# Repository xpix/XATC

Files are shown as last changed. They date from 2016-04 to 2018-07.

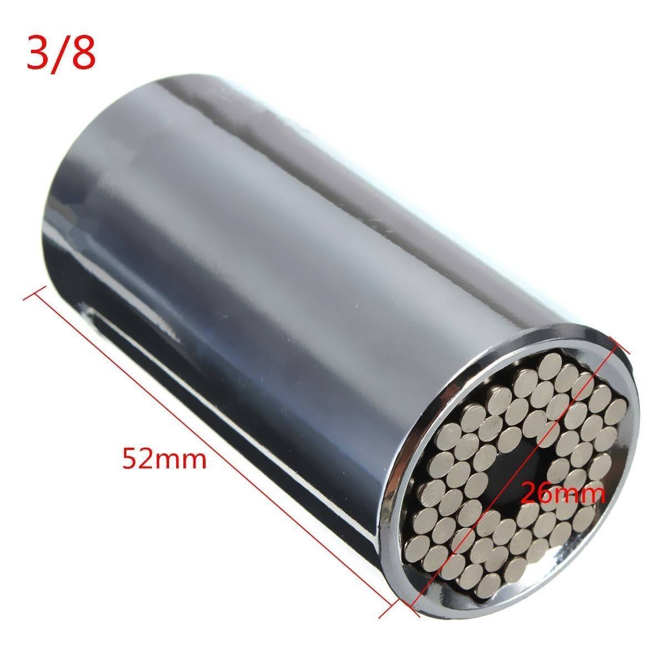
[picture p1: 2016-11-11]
pics/61zgxAEAy0L._SL1200_.jpg

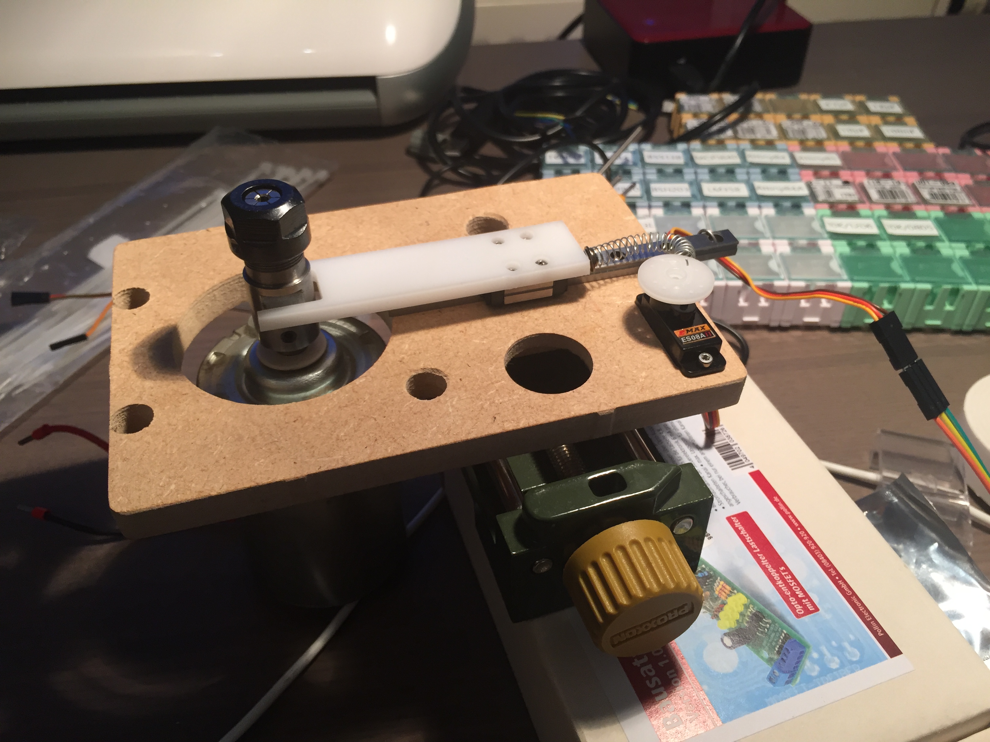
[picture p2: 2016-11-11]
pics/IMG_0800.JPG

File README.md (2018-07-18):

XATC
====

For my XDisPlace project i try to find a good solution to bring all (Mill, Cut, Drill, Solder dispense, Solder) processes together. 
I wrote a ToDo what i need to bring this project to fly. I realized, all what i need it's just to find a solution for an Automatic Tool Changer (ATC).
Here i try to describe all steps how you can build your own XATC.

Full endmill change (https://www.youtube.com/watch?v=-IGAYd8OnOE)

![Some Prototypes](https://lh3.googleusercontent.com/1o3ptjsWJQUGR22RlypUTsi2ktSJ3byGEMolx_pXxnDRvq5ogUWD7ulUHWkvxa8qtrL7SXkMepEVHm6FAdkG-Nc4atV2e4KjoQi_63OzVnHIrBEG3auFcek6qWjRMISj2B0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)

Project Links
------------
* Weekly messages on [g+](https://plus.google.com/collection/QX47gB)
* Video sessions on [youtube](https://www.youtube.com/playlist?list=PLYPTUTcLMTK7m0cOoOKlDnuhGV8ONrgo_)
* Web Video log on [blogspot](http://xpixer.blogspot.com/)

Dependencies
------------

* [TinyG as CNC Controller](https://github.com/synthetos/TinyG)
  The first stable version is realized on a tinyGv8.
* [Chilipeppr](http://chilipeppr.com/tinyg)
  This will be needed at runtime to perform the actual tool change.
* [Arduino](https://www.arduino.cc/)
  Only required for Servo control support.
* [CNC3040](http://www.ebay.com/bhp/cnc-3040z)
  The hardware platform that i use for this project

Components
----------
On the follow pages i'll describe the diy mechanical parts that you can mill on your CNC3040.

* [Spindle lock platform](https://github.com/xpix/XATC/wiki/Spindle-lock-platform)
  All about lock the spindle, drafts, software and BOM List's
* [XATC Carousel](https://github.com/xpix/XATC/wiki/XATC-Carousel)
  All about the central component, the xatc carousel ...

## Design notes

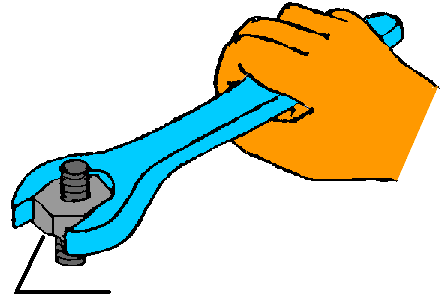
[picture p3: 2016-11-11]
pics/Hebel_Bild_12.gif

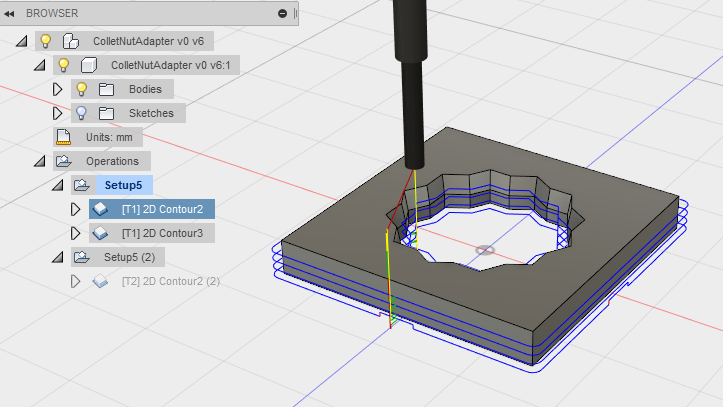
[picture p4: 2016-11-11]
pics/FusionSimulate.PNG

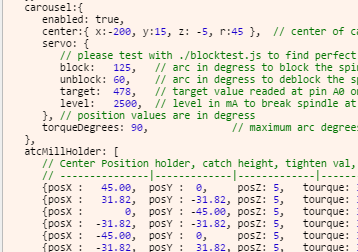
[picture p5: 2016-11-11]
pics/code.PNG

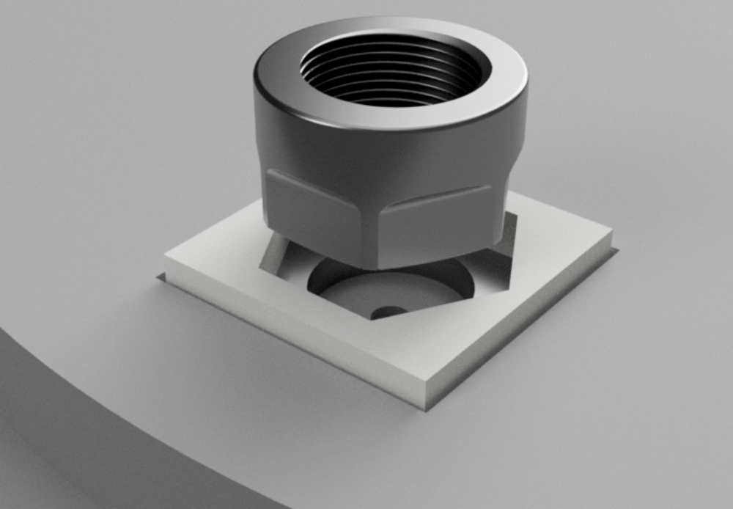
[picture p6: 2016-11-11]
pics/CarouselV2 v6.png

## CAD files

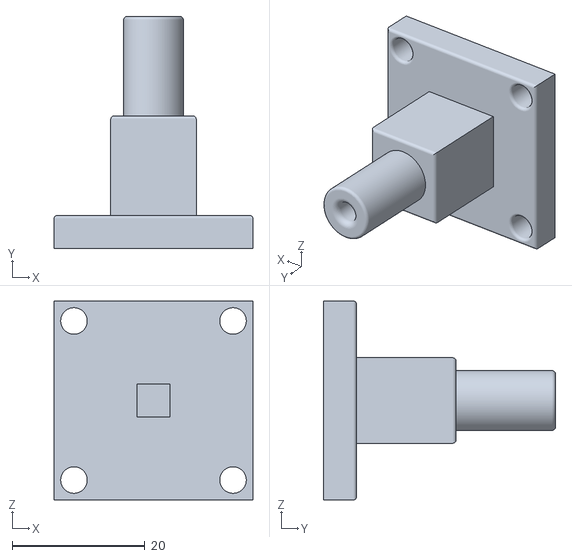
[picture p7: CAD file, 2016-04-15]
fusion360/XTC-Holder.stl
30.0 x 35.0 x 30.0

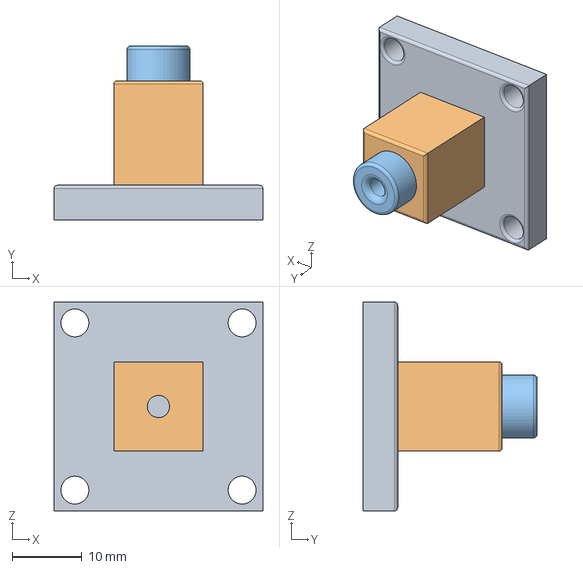
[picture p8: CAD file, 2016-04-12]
fusion360/XTC-Holder v0.step
30.0 x 25.0 x 30.0 mm

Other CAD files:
fusion360/GatorGripAdapter v2.f3d
fusion360/XTC-Holder v0.iges
fusion360/XTC-Holder.f3d

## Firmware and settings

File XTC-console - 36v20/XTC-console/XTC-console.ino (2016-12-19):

/*
The XTC Console program to communicate between chilipeppr and motordriver. 
Use a normal arduino nano at this time and send textcommands (a kind of g-code for spindle)
Please use this DC Controller (30A High Power Single way H-bridge DC Motor Driver Module) http://www.ebay.com/itm/131528092776 
and a ACS712 Current sensor

Use this pinout:
ACS712: 
  VCC --> 5V
  SIG --> A0
  3.3 --> A5
  GND --> GND

DC Controller
  GND --> GND
  PA  --> D9
  A1  --> D2
  A2  --> D4

PWM Signal from CNC Controller
  PWM --> D3
  GND --> GND
  
*/

// Demo Code for SerialCommand Library Steven Cogswell May 2011
// https://github.com/scogswell/ArduinoSerialCommand

#include "SerialCommand.h"
#include "HighPowerMotorDriver.h"
#include "Timer.h"
#include <Servo.h>


#define servoPin A0           // Arduino Servo Pin
#define arduinoLED 13         // Arduino LED on board
#define pwmPin 3              // PWM read pin

#define defaultSpeed 100      // Default speed for spindle
#define defaultBreak 400      // Default power for breake 
#define interval 50           // interval in milliseconds to test the motor current

int level   = 0;
int currentEvent;
int debugEvent;
int speed;
int saved_speed;
int pwm_value;
int speedTimer;


SerialCommand SCmd;        // The SerialCommand object
HighPowerMotorDriver md;
Timer timer;               // The timer object
Servo myservo;                // create servo object to control a servo

void servo_control()
{
  int pos = 91;
  char *arg = SCmd.next();    // Get the next argument from the SerialCommand object buffer
  if (arg != NULL)      // As long as it existed, take it
  {
      pos = atol(arg);
  }

  spindle_pwm(false);
  myservo.write(pos); 
  delay(100);   

  ok();
}


// fwd 400 500
void spindle_forward()
{
  speed = defaultSpeed;
  spindle_pwm(false);

  char *arg = SCmd.next();    // Get the next argument from the SerialCommand object buffer
  if (arg != NULL)      // As long as it existed, take it
  {
      speed = atol(arg);
  }
  else if(saved_speed) {
      speed = saved_speed;
  }

  // Timer parameter 
  arg = SCmd.next();
  int timee = 0;
  if (arg != NULL){
    timee = atol(arg);
    callTimer(timee);
  }

  spindle_status(speed, timee);

  md.setSpeed(speed);
  ok();
}

// bwd 400 500
void spindle_backward()
{
  speed = (0 - defaultSpeed);
  spindle_pwm(false);

  char *arg = SCmd.next();    // Get the next argument from the SerialCommand object buffer
  if (arg != NULL)      // As long as it existed, take it
  {
      speed = (0 - atol(arg));
  }
  else if(saved_speed) {
      speed = saved_speed;
  }

  // Timer parameter 
  arg = SCmd.next();
  int timee = 0;
  if (arg != NULL){
    timee = atol(arg);
    callTimer(timee);
  }

  spindle_status(speed, timee);

  md.setSpeed(speed);
  ok();
}

void spindle_jitter()
{
  int time = 0;
  int speed = 0;
  spindle_pwm(false);

  // Speed parameter 
  char *arg = SCmd.next();    // Get the next argument from the SerialCommand object buffer
  if (arg != NULL)      // As long as it existed, take it
  {
      speed = atol(arg);
  }

  // Timer parameter 
  arg = SCmd.next();
  if (arg != NULL){
    time = atol(arg);
  }

  // jitter one times forward i.e. speed 200 - time 100ms
  saved_speed = speed;
  spindle_forward();                      // drive spindle forward
  timer.after(time, spindle_break);       // 100ms: break spindle

  // ... and backward
  saved_speed = (0 - speed);
  timer.after(time+10, spindle_backward); // 110ms: drive spindle backward
  timer.after((time*2)+10, spindle_break);// 210ms: break spindle
}

// brk 300
void spindle_break()
{
  int breake = defaultBreak;
  spindle_pwm(false);

  char *arg = SCmd.next();    // Get the next argument from the SerialCommand object buffer
  if (arg != NULL)      // As long as it existed, take it
  {
      breake = atol(arg);
  }

  spindle_status(0, -1);
  
  md.setBrake();
  ok();
}

void set_dbg(){
  int dbg_interval = interval;
  char *arg = SCmd.next();    // Get the next argument from the SerialCommand object buffer
  if (arg != NULL)      // As long as it existed, take it
  {
      dbg_interval = atol(arg);
  }
  if(debugEvent){
      timer.stop(debugEvent);
      debugEvent = 0;
  }
  else {
      debugEvent = timer.every(dbg_interval, spindle_status);
  }
  ok();   
}

// sta
void spindle_status()
{
  spindle_status(0,0);
}

void spindle_status(int speed, int timee)
{
  int ma    = md.getCurrentMilliamps();

  Serial.print("Sp: "); 
  Serial.print(speed); 
  Serial.print("\t"); 

  Serial.print("PWM: "); 
  Serial.print(pwm_value); 
  Serial.print("\t"); 

  Serial.print("Tim: "); 
  Serial.print(timee); 
  Serial.print(" ms"); 
  Serial.print("\t"); 

  Serial.print("Cur: "); 
  Serial.print(ma); 
  Serial.print(" mA"); 
  Serial.print("\t"); 

  Serial.print("Lev: "); 
  Serial.print(level); 

  Serial.println(); 
}

// lev 3000
void spindle_set_breaklevel(){
  char *arg = SCmd.next();    // Get the next argument from the SerialCommand object buffer
  if (arg == NULL)      // As long as it existed, take it
  {
     Serial.print(F("lev: ")); 
     Serial.println(level); 
  }
  else{
      level = atol(arg);
  }
  ok();   
}

// tim 1000
// stop spindle after x milliseconds
void spindle_set_stoptime(){
  char *arg = SCmd.next();    // Get the next argument from the SerialCommand object buffer
  if (arg == NULL)      // As long as it existed, take it
  {
     Serial.print(F("tim: millisceonds")); 
  }
  else{
      int time = atol(arg);
      int waitEvent = callTimer(time);
  }
  ok();   
}

int callTimer(int time){
  return timer.after(time, spindle_break);
}

void ok(){
  Serial.println("OK"); 
}

void checkCurrent(){
   if( level > 0 && md.getCurrentMilliamps() >= level){
      timer.stop(currentEvent);
      md.setBrake(); // full brake
      level = 0;          // reset level
      currentEvent = timer.every(interval, checkCurrent);
   }

   if( level < 0 && md.getCurrentMilliamps() <= (0 - level)){
      timer.stop(currentEvent);
      md.setBrake(); // full brake
      level = 0;          // reset level
      currentEvent = timer.every(interval, checkCurrent);
   }
}

void set_led(){
  if(digitalRead(arduinoLED)){
      digitalWrite(arduinoLED,LOW);
  }
  else {
      digitalWrite(arduinoLED,HIGH);
  }
  ok();   
}

void spindle_pwm(){
  char *arg = SCmd.next();    // Get the next argument from the SerialCommand object buffer
  if (arg == NULL)            // As long as it existed, take it
  {
     spindle_pwm(true);
  }
  else
  {
     spindle_pwm(false);
  }
}

void spindle_pwm(bool active){
   if(active){
      // set a timer he read the pwm signal and set the spindle speed
      if(pwm_value > 0){
        md.setSpeed(pwm_value);
      } else {
        md.setSpeed(0);
      }
      speedTimer = timer.after(250, spindle_pwm);
   }else{
      if(speedTimer){
         timer.stop(speedTimer);
         speedTimer = 0;
         md.setSpeed(0);
      }
   }
}


// This gets set as the default handler, and gets called when no other command matches. 
void unrecognized()
{
  Serial.println(F("? use commands: fwd[S,T], bwd[S,T], jit[S,T] brk[I], sta, lev, tim[ms], srv[deg], dbg, sav, rem")); 
}

void setup()
{  
  pinMode(arduinoLED,OUTPUT);      // Configure the onboard LED for output
  digitalWrite(arduinoLED,LOW);    // default to LED off

  pinMode(pwmPin, INPUT);          // Pin to read PWM Value from CNC Controller

  Serial.begin(115200); 

  // Initialize Servo
  myservo.attach(servoPin);

  // Initialize motordriver
  md.init();

  // Setup callbacks for SerialCommand commands 
  SCmd.addCommand("srv",servo_control);         // Send commands to servo
  SCmd.addCommand("fwd",spindle_forward);       // Turns spindle on and rotate forward
  SCmd.addCommand("bwd",spindle_backward);      // Turns spindle on and rotate backward
  SCmd.addCommand("jit",spindle_jitter);        // Turns spindle rotate forward and backward
  SCmd.addCommand("brk",spindle_break);         // Turns Spindle w/ break power or defaultBreak
  SCmd.addCommand("sta",spindle_status);        // get milliamps and direction ...
  SCmd.addCommand("lev",spindle_set_breaklevel);// Set the level off millAmpere , the spindle will break
  SCmd.addCommand("tim",spindle_set_stoptime);  // Set delay to stop
  SCmd.addCommand("led",set_led);               // Set led on/off
  SCmd.addCommand("dbg",set_dbg);               // Set debug output
  SCmd.addCommand("pwm",spindle_pwm);           // set  --- "" --------

  // Interval to read current and stop spindle if rise over level
  currentEvent = timer.every(interval, checkCurrent);


  SCmd.addDefaultHandler(unrecognized);  // Handler for command that isn't matched  (says "What?") 
  Serial.println(F("XTC-Console 0.2 ready")); 

}


// Define the number of samples to keep track of.  The higher the number,
// the more the readings will be smoothed, but the slower the output will
// respond to the input.  Using a constant rather than a normal variable lets
// use this value to determine the size of the readings array.
const int numReadings = 10;

int readings[numReadings];      // the readings from the analog input
int readIndex = 0;              // the index of the current reading
int total = 0;                  // the running total

void loop()
{  
  SCmd.readSerial();     // We don't do much, just process serial commands

  // read sindle speed PWM pin and translate from 0 ... 400 
  /*
   * 0rpm or off    =     <1100
   * 1000rpm        =     1245
   * 12000rpm       =     2000
   */
  int pwm = pulseIn(pwmPin, HIGH);

  // subtract the last reading:
  total = total - readings[readIndex];
  // read from the sensor:
  readings[readIndex] = pwm;
  // add the reading to the total:
  total = total + readings[readIndex];
  // advance to the next position in the array:
  readIndex = readIndex + 1;

  // if we're at the end of the array...
  if (readIndex >= numReadings) {
    pwm_value = map(total / numReadings, 1100, 2000, 0, 40)*10;
    //pwm_value = total / numReadings;

    // ...wrap around to the beginning:
    readIndex = 0;
  }

  // calculate the average:
  delay(1);
  
  timer.update();
}

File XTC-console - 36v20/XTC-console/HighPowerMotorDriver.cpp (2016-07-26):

#include "HighPowerMotorDriver.h"

// Datasheet
// http://www.allegromicro.com/en/Products/Motor-Driver-And-Interface-ICs/Brush-DC-Motor-Drivers/~/media/Files/Datasheets/A3941-Datasheet.ashx

// Constructors ////////////////////////////////////////////////////////////////

HighPowerMotorDriver::HighPowerMotorDriver()
{
  //Pin map
  _DIR   = 4;
  _PWML  = 5;
  _PWMH  = 6;
  _FF1   = 7;
  _FF2   = 8;
  _CS    = A7; 
}

HighPowerMotorDriver::HighPowerMotorDriver(
      unsigned char DIR, 
      unsigned char PWMH, 
      unsigned char PWML, 
      unsigned char FF1,
      unsigned char FF2,
      unsigned char CS)
{
   //Pin map
   //PWM1 and PWM2 cannot be remapped because the library assumes PWM is on timer1
   _DIR  = DIR;
   _PWMH = PWMH;
   _PWML = PWML;
   _FF1  = FF1;
   _FF2  = FF2;  
}

// Public Methods //////////////////////////////////////////////////////////////
void HighPowerMotorDriver::init()
{
// Define pinMode for the pins and set the frequency for timer1.

  pinMode(_DIR,   OUTPUT);
  pinMode(_PWMH,  OUTPUT);
  pinMode(_PWML,  OUTPUT);
  pinMode(_FF1,   INPUT);
  pinMode(_FF2,   INPUT);
  pinMode(_CS,    INPUT);


  /*
  Sign-magnitude (drive-brake):  With PWML  disconnected or  held high,  apply a
  pulse-width-modulated (PWM) signal to the PWMH pin. The duty cycle of the  PWM
  controls the speed of the motor and the DIR pin controls the direction. During
  the active (high)  portion of the  PWM, the motor  outputs drive the  motor by
  putting the full V+  voltage across the motor  in the direction determined  by
  the DIR pin; during  the low portion of  the PWM, the motor  outputs brake the
  motor by shorting both  motor terminals to ground.  This means that the  motor
  alternates between drive and brake at the PWM frequency with the percentage of
  the driving time determined by the duty cycle.
  */

  digitalWrite(_PWML, HIGH); // default to on
}

// Set speed for motor, speed is a number betwenn -400 and 400
void HighPowerMotorDriver::setSpeed(int speed)
{
  unsigned char reverse = 0;
  digitalWrite(_PWML,1);
  
  if (speed < 0)
  {
    speed = -speed;  // Make speed a positive quantity
    reverse = 1;  // Preserve the direction
  }
  if (speed > 400)  // Max PWM dutycycle
    speed = 400;
  analogWrite(_PWMH,speed * 51 / 80); // default to using analogWrite, mapping 400 to 255
  if (reverse)
    digitalWrite(_DIR,HIGH);
  else
    digitalWrite(_DIR,LOW);
}

// Set speed for motor, speed is a number betwenn -400 and 400
void HighPowerMotorDriver::setBrake()
{
    analogWrite(_PWMH,255);
    digitalWrite(_PWML,0);
}

// Return motor 1 current value in milliamps.
double HighPowerMotorDriver::getCurrentMilliamps()
{
  int sensorValue = analogRead(_CS); // 0.00 // Read  analog value
  // convert to milli amps
  float outputValue =  (sensorValue  - 512) * 0.037054326; // 0.074054326 /2 seems better
  return abs(outputValue*1000);
 }

// Return error status
unsigned char HighPowerMotorDriver::getFault()
{
   bool ff1 = digitalRead(_FF1);
   bool ff2 = digitalRead(_FF2);
   if(!ff1 && ff2){
      return 1; // Short circuit
   }
   if(ff1 && !ff2){
      return 2; // Over temperature
   }
   if(ff1 && ff2){
      return 3; // Under Voltage
   }

   return 0;
}

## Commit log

2016-04-12 -initial version
    [XTC-Holder v0.iges, XTC-Holder v0.step, XTC-Holder.f3d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]
2016-04-15 - changes for new adapter
    [XTC-Holder.stl]
2016-04-20 add some comments to discover the correct timing
    [macro.js]
2016-04-20 add complex flow to have accurate control
2016-04-20 fix tighten/loosed event
2016-04-20 fix some timing's and wait for a practical test at home :)
    [macro.js]
2016-04-20 add more time in nut to tight collet
    [macro.js]
2016-04-22 complete rewrite to $.when.done Events create a thread for this https://groups.google.com/d/msg/chilipeppr/NvnD-yJ6skI/mfhmZoowAQAJ
2016-04-22 some fixes in timing
    [macro.js]
2016-04-22 some tests and fixes
    [macro.js]
2016-04-23 Some fixes and changes
    [macro.js]
2016-04-25 Use new commands to screw and unscrew the collet.
2016-04-25 Fix load external script one times and ignore same tool if atc happend
    [macro.js]
2016-04-28 add and load external spindle controller
2016-04-28 stop spindle before and restart after atc
2016-05-09 add arc calculation and servo function
2016-05-16 fix center of 3d objects
    [macro.js]
2016-05-17 first unblock servo at init
2016-05-17 unblock if finished and dont start spindle
2016-05-17 arc fix to float numbers
    [macro.js]
2016-05-18 fix the arc calculation
    [macro.js]
2016-05-19 use rounded values in every case to compare the event position
2016-05-19 if condition if screw or unscrew
2016-05-20 many fixes for real tests
    [macro.js]
2016-05-23 lot of changes at xtc-console and add new servo controller via esp8266
2016-05-24 add target value to control the servo position
2016-05-24 rotate slow backwards for block spindle
2016-05-25 servo has to move to zero position if block failed
    [macro.js]
2016-06-12 set feedrate to low and add more power to steppers
2016-06-12 use flag 'screw' for true or false (unscrew)
2016-06-15 add button for tdb table
2016-06-20 add two new commands for save and remember last spindle status
2016-06-20 fix this = that
    [macro.js]
2016-06-20 fix directory variable, obsolete cuz speed can be negative
    [XTC-console.ino]
2016-06-21 fix button icon
2016-07-05 Add jitter function: 'jit speed milliseconds' and improve status
    [XTC-console.ino]
2016-07-11 add jitter,save and remember function
    [XTC-console.ino]
2016-07-11 add pin for servo position
2016-07-11 add new pololu motor driver for 36v20
2016-08-12 replace parameter for xatc 0.2 and add usage for tls
    [macro.js]
2016-08-18 add jitter to catch frame AFTER blocking spindle
    [macro.js]
2016-08-27 add 0.25 mm to jitter spindle second time and hold in wrench
    [macro.js]
2016-08-29 add methods screw and unscrew for call magic move and some additional actions
2016-09-09 some fixes to screw
    [macro.js]
2016-09-15 add Servo control to DC Controller for direct control
2016-09-15 Improve Speed, direct control servo, more tourque
2016-10-15 add touchprobe sensor process
2016-10-21 fix spindle status
2016-10-23 add probed and move touch probe method to correct place
    [macro.js]
2016-10-24 add servo control
2016-10-25 add control pwm solution
2016-11-10 add a lot of new files and scripts
    [GatorGripAdapter v2.f3d]
2016-11-10 Add XTC-Console for new ebay 36V Dual driver
2016-11-11 remove unsed code and set via pwm spindle at end of toolchange
2016-11-18 fix parse fusion gcode and make grbl compatible
    [macro.js]
2016-12-19 try backward catching for 15° to catch better collet in nut
2016-12-19 remove relation to tool length sensor
2016-12-21 cr at pwm
2016-12-21 set spindle speed after every toolchange
2016-12-21 set spindle speed
2017-01-22 set spindle block in touchprobe event
2017-01-22 fix feedrate for g1
    [macro.js]
2017-01-22 stop spindle after catch endmill
2017-02-20 add probe.js as simple macro for xatv04
2017-02-22 add new probe macro for gcode pure xatcv04
2018-07-18 cleanup for finished version
    [XTC-Holder.stl]
